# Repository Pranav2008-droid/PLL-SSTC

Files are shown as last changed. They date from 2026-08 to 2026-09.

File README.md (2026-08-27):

# PLL SSTC

## Overview
The PLL SSTC stands for Phase Locked Loop Solid State Tesla coil. This device produces high voltage sparks that resemble lightning by exciting a secondary coil at its resonant frequency.

This system tracks the resonant frequency using a Phase Locked Loop (PLL) IC: CD4046. It uses the output from the PLL to drive a full bridge switching circuit at around 300-325VDC.

It also has the capability to play audio through both Amplitude Modulation (AM) and Frequency Modulation (FM). It operates at 250kHz and should switch power in the Kilowatt range.




> ⚠️ High Voltage Warning  
> This project involves potentially lethal voltages and high-frequency/high-power switching. Do not build or operate it unless you understand the relevant electrical safety risks.

## Gate Driver
I'm using a TC4428 paired with 2 N-channel/P-channel dual MOSFET ICs to produce an amplified signal capable of producing higher driving currents. Any MOSFET driving IC with one inverting and one non-inverting output should work in the PCB, such as the UCC27425.

## GDT
The Gate Drive Transformer must be large enough to not saturate from driving currents and be of the correct material to work properly under such high frequencies.

## Mosfets
My circuit shows IRFP460s as the full bridge switches, but they are a bit outdated and inefficient. Much better alternatives exist — IGBTs can also be used instead.

## Primary
Make sure the primary impedance is high enough such that your switches can handle the currents.

## Demo
Demo of the amplitude modification music played through an attiny interupter: https://www.youtube.com/shorts/cHrE9xm2R9Q

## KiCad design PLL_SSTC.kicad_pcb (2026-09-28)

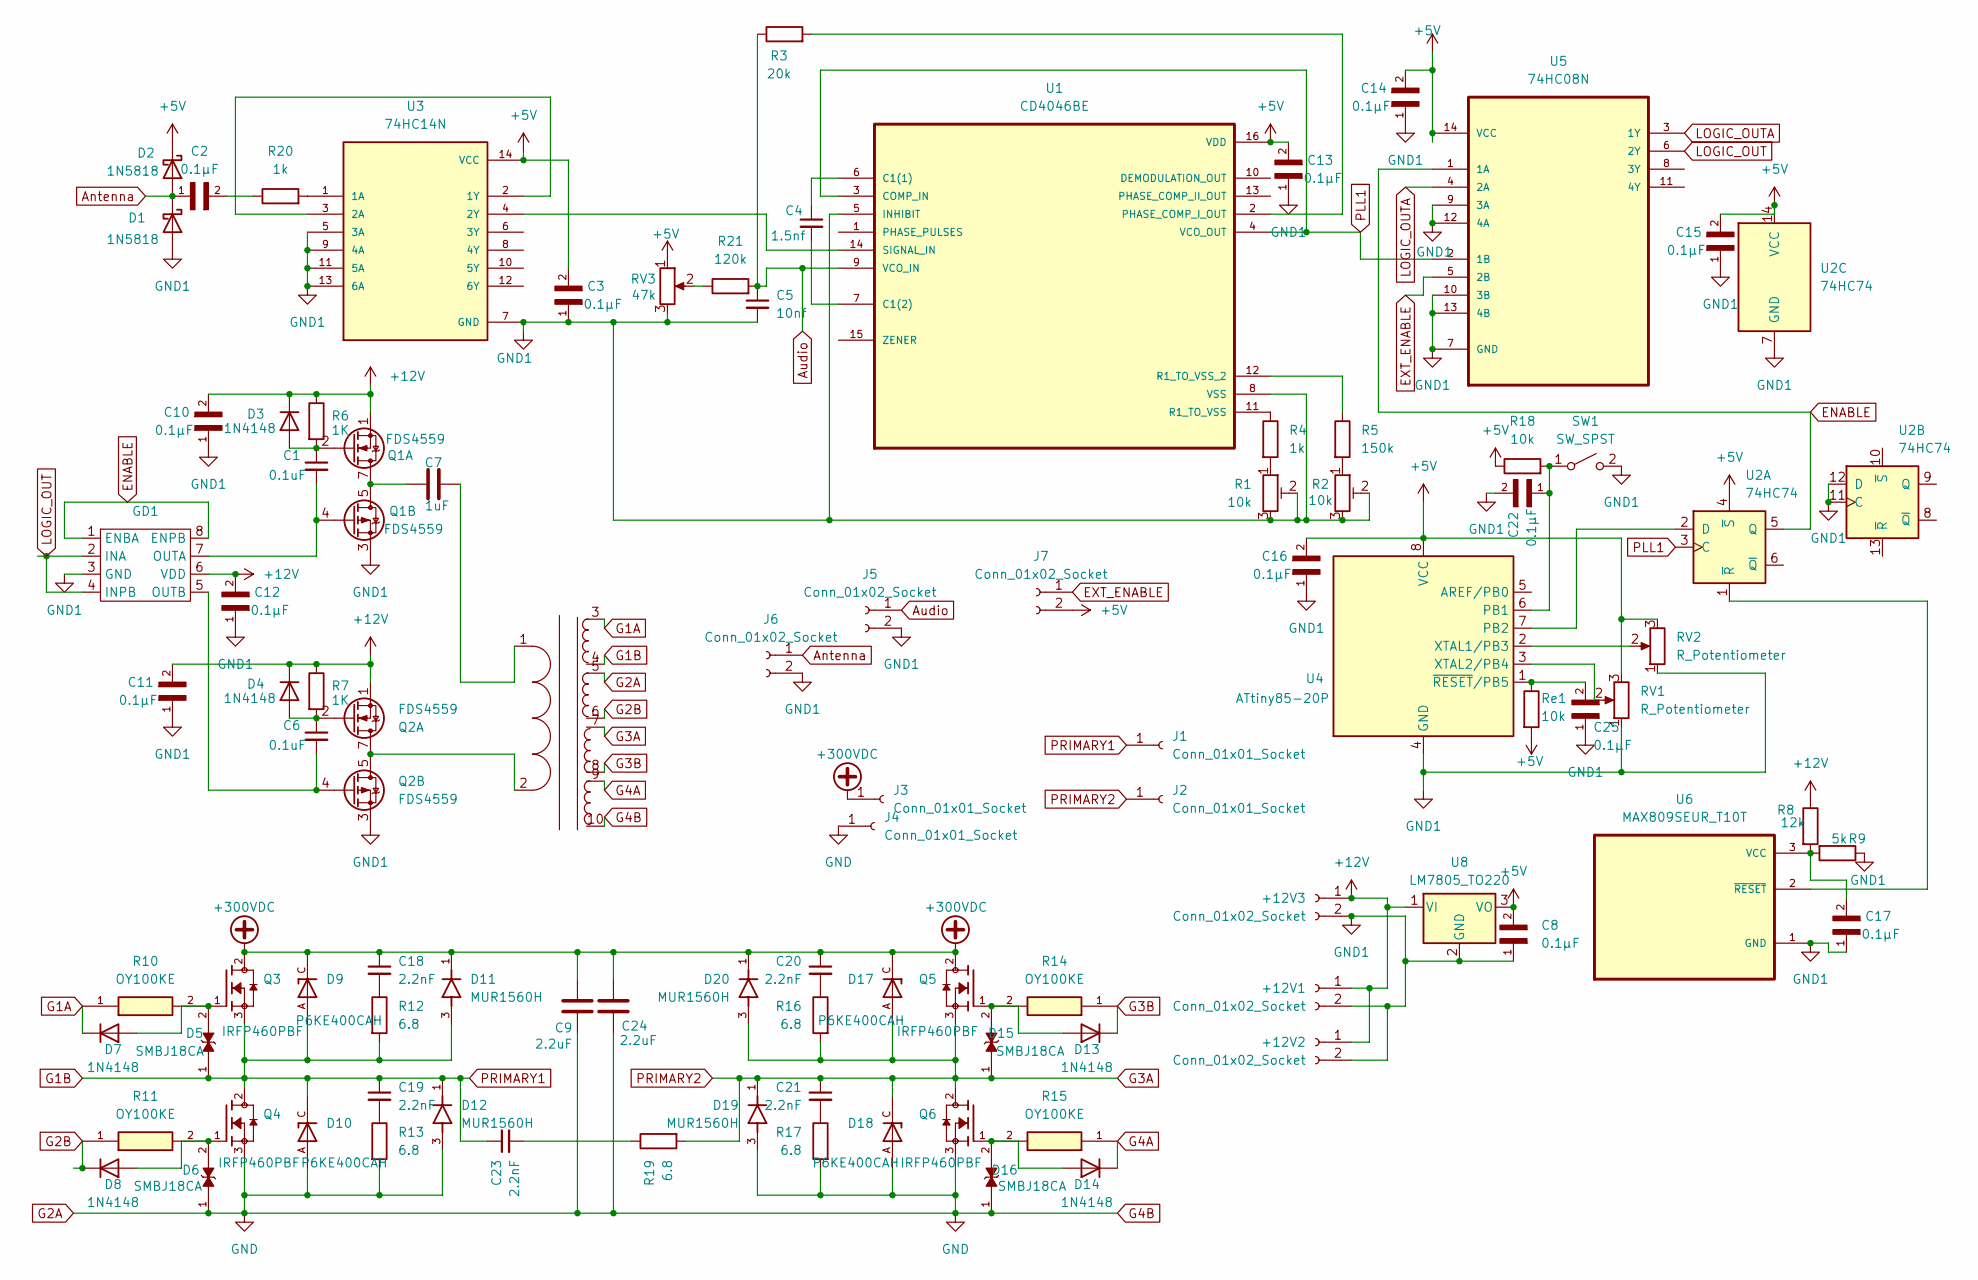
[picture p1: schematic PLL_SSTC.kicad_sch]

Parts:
+12V1, +12V2, +12V3: Conn_01x02_Socket; PinHeader_1x02_P2.54mm_Vertical
C1, C6: 0.1uF; C_0603_1608Metric_Pad1.08x0.95mm_HandSolder
C2, C3, C8, C10, C11, C12, C13, C14, C15, C16, C17, C22, C25: 0.1µF; C_0603_1608Metric_Pad1.08x0.95mm_HandSolder; PARTREV 081816
C4: 1.5nf; C_Rect_L7.0mm_W2.5mm_P5.00mm
C5: 10nf; C_Rect_L7.0mm_W2.5mm_P5.00mm
C7: 1uF; C_Rect_L31.5mm_W15.0mm_P27.50mm_MKS4
C9, C24: 2.2uF; C_Rect_L31.5mm_W15.0mm_P27.50mm_MKS4
C18, C19, C20, C21, C23: 2.2nF; C_Rect_L7.0mm_W2.5mm_P5.00mm
D1, D2: 1N5818; D_DO-41_SOD81_P10.16mm_Horizontal
D3, D4, D7, D8, D13, D14: 1N4148; D_DO-35_SOD27_P7.62mm_Horizontal
D5, D6, D15, D16: SMBJ18CA; DIOM4336X265N; PARTREV I2102
D9, D10, D17, D18: P6KE400CAH; DIOAD1300W80L670D310; PARTREV K2105
D11, D12, D19, D20: MUR1560H; TO508P997X444X1905-2; PARTREV F
GD1: DIP-8_W7.62mm_LongPads
J1, J2, J3, J4: Conn_01x01_Socket; SolderWire-4sqmm_1x01_D3mm_OD6mm
J5, J6, J7: Conn_01x02_Socket; TerminalBlock_Phoenix_MKDS-3-2-5.08_1x02_P5.08mm_Horizontal
Q1, Q2: FDS4559; SOIC-8_3.9x4.9mm_P1.27mm
Q3, Q4, Q5, Q6: IRFP460PBF; TO546P1587X531X2511-3; PARTREV A
R1, R2: 10k; TRIM_3296W-1-250
R3: 20k; R_Axial_DIN0207_L6.3mm_D2.5mm_P10.16mm_Horizontal
R4, R20: 1k; R_Axial_DIN0207_L6.3mm_D2.5mm_P10.16mm_Horizontal
R5: 150k; R_Axial_DIN0207_L6.3mm_D2.5mm_P10.16mm_Horizontal
R6, R7: 1K; R_Axial_DIN0207_L6.3mm_D2.5mm_P10.16mm_Horizontal
R8: 12k; R_Axial_DIN0207_L6.3mm_D2.5mm_P10.16mm_Horizontal
R9: 5k; R_Axial_DIN0207_L6.3mm_D2.5mm_P10.16mm_Horizontal
R10, R11, R14, R15: OY100KE; R_Axial_DIN0414_L11.9mm_D4.5mm_P7.62mm_Vertical; MOUSER_PART_NUMBER 588-OY-10-E
R12, R13, R16, R17, R19: 6.8; R_Axial_DIN0922_L20.0mm_D9.0mm_P7.62mm_Vertical
R18: 10k; R_Axial_DIN0207_L6.3mm_D2.5mm_P10.16mm_Horizontal
R21: 120k; R_Axial_DIN0207_L6.3mm_D2.5mm_P10.16mm_Horizontal
RV1, RV2: R_Potentiometer; Potentiometer_Bourns_3296X_Horizontal
RV3: 47k; Potentiometer_Bourns_3296X_Horizontal
Re1: 10k; R_Axial_DIN0204_L3.6mm_D1.6mm_P1.90mm_Vertical
SW1: SW_SPST; TerminalBlock_4Ucon_1x02_P3.50mm_Horizontal
U1: CD4046BE; DIP794W45P254L1969H508Q16
U2: 74HC74; CERDIP-14_W7.62mm_SideBrazed_LongPads_Socket
U3: 74HC14N; DIP764W47P254L1920H431Q14
U4: ATtiny85-20P; DIP-8_W7.62mm
U5: 74HC08N; DIP254P762X420-14; MPN 74HC08N
U6: MAX809SEUR_T10T; SOT95P237X112-3N
U7: GDT_1P4S
U8: LM7805_TO220; TO-220-3_Vertical

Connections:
+5V: C3.2, C8.2, C13.2, C14.2, C15.2, C16.2, D2.1 (K), J7.2, R18.1, RV1.3, RV2.3, RV3.1, Re1.2, U1.16 (VDD), U2.4 (~S), U2.14 (VCC), U3.14 (VCC), U4.8 (VCC), U5.14 (VCC), U8.3 (VO)
+12V: +12V1.1, +12V2.1, +12V3.1, C10.2, C11.2, C12.2, D3.1 (K), D4.1 (K), GD1.6 (VDD), Q1.1 (S1), Q2.1 (S1), R6.1, R7.1, R8.1, U8.1 (VI)
+300VDC: C9.1, C18.1, C20.1, C24.1, D9.C, D11.1, D17.C, D20.1, J3.1 (Pin_1_1), Q3.2, Q5.2
Antenna: C2.1, D1.1 (K), D2.2 (A), J6.1
Audio: C5.1, J5.1, R3.1, R21.2, U1.9 (VCO_IN)
ENABLE: GD1.1 (ENBA), GD1.8 (ENPB), U2.5 (Q), U5.1 (1A)
EXT_ENABLE: J7.1, U5.5 (2B)
G1A: D7.1 (K), R10.1, U7.3 (1A)
G1B: C19.1, C23.1, D5.1, D9.A, D10.C, D11.3, D12.1, J1.1 (Pin_1_1), Q3.3, Q4.2, R12.2, U7.4 (1B)
G2A: C9.2, C24.2, D6.1, D10.A, D12.3, D16.1, D18.A, D19.3, J4.1 (Pin_1_1), Q4.3, Q6.3, R13.2, R17.2, U7.5 (2A), U7.10 (4B)
G2B: D8.1 (K), R11.1, U7.6 (2B)
G3A: C21.1, D15.1, D17.A, D18.C, D19.1, D20.3, J2.1 (Pin_1_1), Q5.3, Q6.2, R16.2, R19.2, U7.7 (3A)
G3B: D13.1 (K), R14.1, U7.8 (3B)
G4A: D14.1 (K), R15.1, U7.9 (4A)
GND1: +12V1.2, +12V2.2, +12V3.2, C3.1, C5.2, C8.1, C10.1, C11.1, C12.1, C13.1, C14.1, C15.1, C16.1, C17.1, C22.2, C25.1, D1.2 (A), GD1.3 (GND), J5.2, J6.2, Q1.3 (S2), Q2.3 (S2), R1.2, R1.3, R2.2, R2.3, R9.1, RV1.1, RV2.1, RV3.3, SW1.2 (B), U1.5 (INHIBIT), U1.8 (VSS), U2.7 (GND), U2.11 (C), U2.12 (D), U3.5 (3A), U3.7 (GND), U3.9 (4A), U3.11 (5A), U3.13 (6A), U4.4 (GND), U5.7 (GND), U5.9 (3A), U5.10 (3B), U5.12 (4A), U5.13 (4B), U6.1 (GND), U8.2 (GND)
LOGIC_OUT: GD1.2 (INA), GD1.4 (INPB), U5.6 (2Y)
LOGIC_OUTA: U5.3 (1Y), U5.4 (2A)
unnamed: C2.2, R20.1
unnamed: C7.1, Q1.5 (D2), Q1.6 (D2), Q1.7 (D1), Q1.8 (D1)
unnamed: C18.2, R12.1
unnamed: C19.2, R13.1
unnamed: C20.2, R16.1
unnamed: C21.2, R17.1
unnamed: C23.2, R19.1
unnamed: C1.1, D3.2 (A), Q1.2 (G1), R6.2
unnamed: C6.1, D4.2 (A), Q2.2 (G1), R7.2
unnamed: D5.2, D7.2 (A), Q3.1, R10.2
unnamed: D6.2, D8.2 (A), Q4.1, R11.2
unnamed: D13.2 (A), D15.2, Q5.1, R14.2
unnamed: D14.2 (A), D16.2, Q6.1, R15.2
unnamed: C1.2, GD1.7 (OUTA), Q1.4 (G2)
unnamed: C6.2, GD1.5 (OUTB), Q2.4 (G2)
unnamed: R1.1, R4.2
unnamed: R2.1, R5.2
unnamed: R21.1, RV3.2
unnamed: C22.1, R18.2, SW1.1 (A), U4.6 (PB1)
unnamed: C4.1, U1.6 (C1(1))
unnamed: C4.2, U1.7 (C1(2))
unnamed: R3.2, U1.2 (PHASE_COMP_I_OUT)
unnamed: R4.1, U1.11 (R1_TO_VSS)
unnamed: R5.1, U1.12 (R1_TO_VSS_2)
unnamed: U1.14 (SIGNAL_IN), U3.4 (2Y)
unnamed: U2.2 (D), U4.7 (PB2)
unnamed: U2.1 (~R), U6.2 (~RESET)
unnamed: R20.2, U3.1 (1A)
unnamed: U3.2 (1Y), U3.3 (2A)
unnamed: RV2.2, U4.2 (XTAL1/PB3)
unnamed: RV1.2, U4.3 (XTAL2/PB4)
unnamed: C25.2, Re1.1, U4.1 (~RESET/PB5)
unnamed: C17.2, R8.2, R9.2, U6.3 (VCC)
unnamed: C7.2, U7.1 (PA)
unnamed: Q2.5 (D2), Q2.6 (D2), Q2.7 (D1), Q2.8 (D1), U7.2 (PB)
PLL1: U1.3 (COMP_IN), U1.4 (VCO_OUT), U2.3 (C), U5.2 (1B)

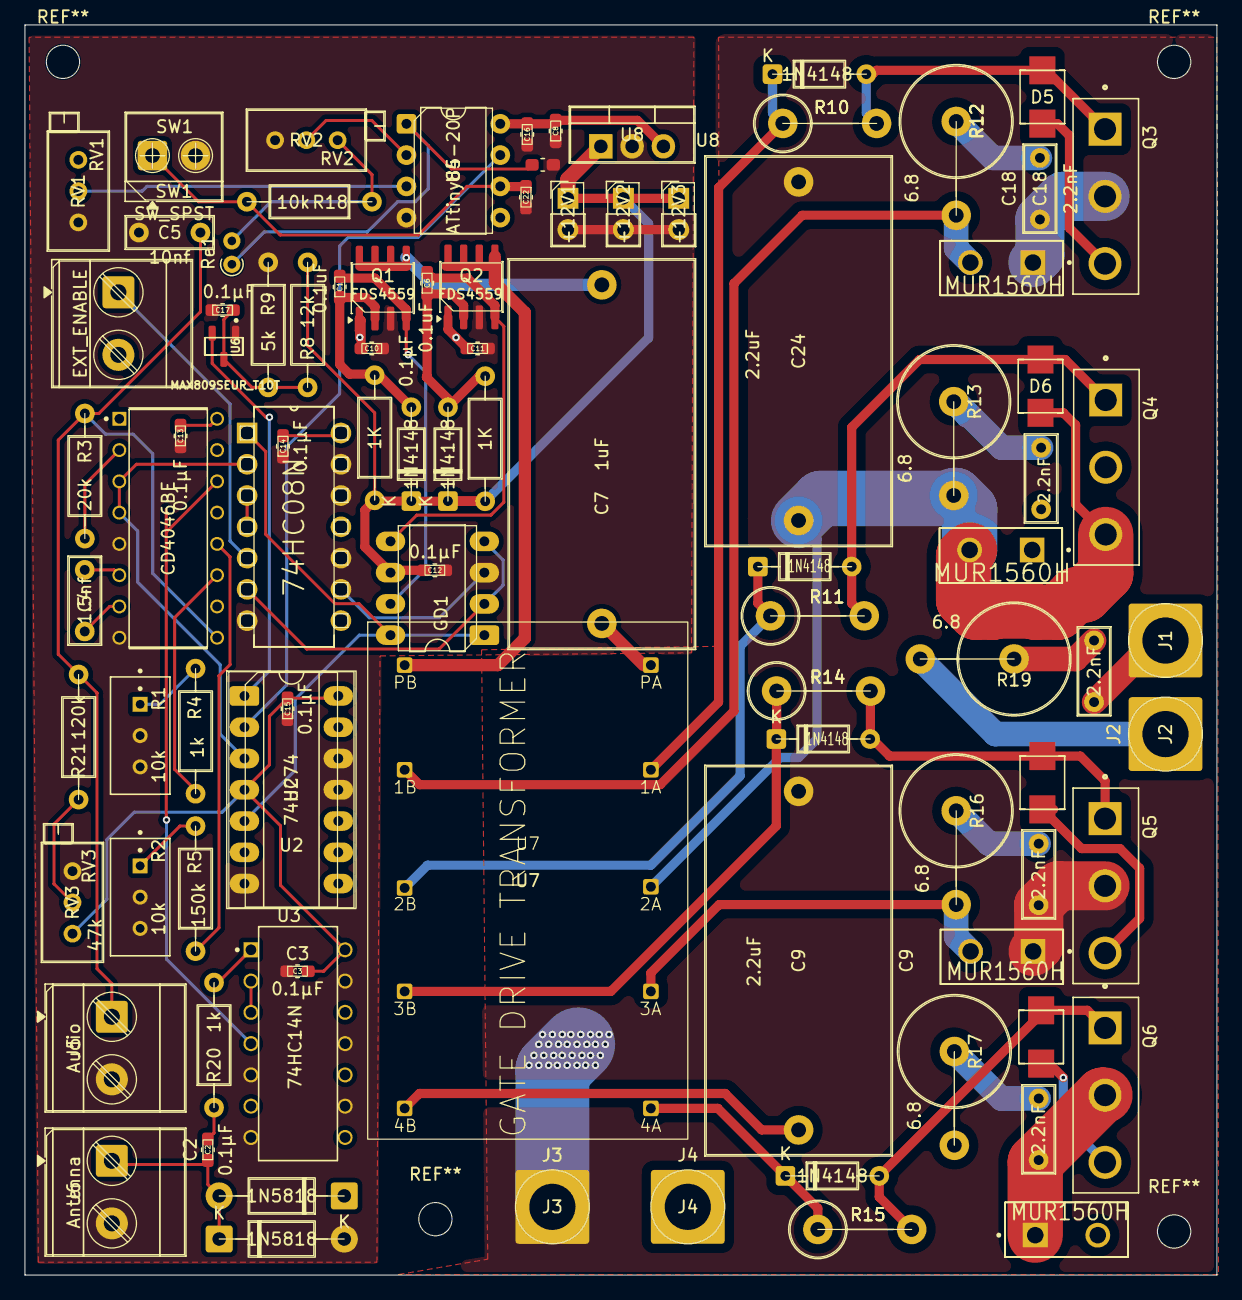
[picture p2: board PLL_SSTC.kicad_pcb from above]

Board: 2 copper layers, 96.8 x 101.5 mm, 92 parts (0 on the bottom side), 53 nets.

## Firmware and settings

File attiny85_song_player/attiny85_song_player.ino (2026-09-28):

/*
 * ATtiny85 SSTC Interrupter (Fixed Tempo, Volume-Only Control)
 * -------------------------------------------------------------------------
 * Pin Map:
 *   A3 (PB3) - Volume / Pulse-Width Potentiometer
 *   D1 (PB1) - Output to Gate Driver / Optocoupler
 * -------------------------------------------------------------------------
 */

#include <avr/io.h>
#include <avr/pgmspace.h>
#include <avr/wdt.h>

#include "song_data.h"

// ---------------- Pin Assignments ----------------
const uint8_t VOL_PIN  = A3;  // Volume pot only
const uint8_t GATE_PIN = 1;   // PB1 -> Optocoupler / Driver

// ---------------- 300V Safety Constraints ----------------
const uint16_t MIN_ON_TIME_US      = 100;  // Minimum for arc breakdown
const uint16_t ABSOLUTE_MAX_ON_US  = 1000; // 1ms pulse width ceiling
const uint16_t MIN_OFF_TIME_US     = 150;  // Gate discharge margin
const uint8_t  MAX_DUTY_CYCLE_PERC = 10;   // Dynamic 10% duty cycle cap

void setup() {
  wdt_disable(); // Watchdog disabled to prevent RF reset loops
  
  pinMode(GATE_PIN, OUTPUT);
  digitalWrite(GATE_PIN, LOW);
  
  pinMode(VOL_PIN, INPUT);
}

void loop() {
  playCompressedSong(full_midi_song, full_midi_song_len);
  delay(1500); // 1.5s delay before repeating
}

void playCompressedSong(const CompressedNote *song, uint16_t len) {
  for (uint16_t i = 0; i < len; i++) {
    uint8_t noteIdx = pgm_read_byte(&song[i].note_idx);
    uint8_t ticks   = pgm_read_byte(&song[i].ticks);
    
    uint16_t freq   = pgm_read_word(&note_freqs[noteIdx]);
    uint32_t dur_ms = (uint32_t)ticks * BASE_TICK_MS; // Fixed 1:1 speed

    playNote(freq, (uint16_t)dur_ms);
    
    digitalWrite(GATE_PIN, LOW);
    
    // Staccato articulation gap between notes
    uint32_t restTime = dur_ms / 10;
    if (restTime > 0) {
      delay(restTime);
    }
  }
}

void playNote(uint16_t freq, uint16_t duration_ms) {
  if (freq == 0 || duration_ms == 0) {
    digitalWrite(GATE_PIN, LOW);
    if (duration_ms > 0) delay(duration_ms);
    return;
  }

  uint32_t periodUs = 1000000UL / freq;
  
  // Calculate dynamic 10% duty cycle limit per note pitch
  uint32_t dutyMaxOn = (periodUs * MAX_DUTY_CYCLE_PERC) / 100;
  uint32_t hardMaxOn = (periodUs > MIN_OFF_TIME_US) ? (periodUs - MIN_OFF_TIME_US) : 0;
  
  uint16_t safeMaxOnTime = ABSOLUTE_MAX_ON_US;
  if (dutyMaxOn < safeMaxOnTime) safeMaxOnTime = (uint16_t)dutyMaxOn;
  if (hardMaxOn < safeMaxOnTime) safeMaxOnTime = (uint16_t)hardMaxOn;

  if (safeMaxOnTime < MIN_ON_TIME_US) {
    safeMaxOnTime = MIN_ON_TIME_US;
  }

  // Read volume potentiometer and enforce safety cap
  uint16_t requestedOnTime = readVolumePulseWidth();
  uint16_t onTime = (requestedOnTime > safeMaxOnTime) ? safeMaxOnTime : requestedOnTime;

  if (onTime >= periodUs) {
    onTime = periodUs / 2;
  }

  uint32_t offTime = periodUs - onTime;
  uint32_t numCycles = ((uint32_t)duration_ms * 1000UL) / periodUs;

  for (uint32_t i = 0; i < numCycles; i++) {
    digitalWrite(GATE_PIN, HIGH);
    delayMicroseconds(onTime);
    
    digitalWrite(GATE_PIN, LOW);
    
    uint32_t remainingOff = offTime;
    while (remainingOff > 10000) {
      delayMicroseconds(10000);
      remainingOff -= 10000;
    }
    delayMicroseconds(remainingOff);
  }
  
  digitalWrite(GATE_PIN, LOW);
}

// Reads Volume Potentiometer (A3) with floor & noise filtering
uint16_t readVolumePulseWidth() {
  uint32_t sum = 0;
  for (uint8_t i = 0; i < 4; i++) {
    sum += analogRead(VOL_PIN);
  }
  uint16_t raw = sum / 4;
  uint16_t val = map(raw, 0, 1023, MIN_ON_TIME_US, ABSOLUTE_MAX_ON_US);
  return (val < MIN_ON_TIME_US) ? MIN_ON_TIME_US : val;
}

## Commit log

2026-08-24 Enhance README with images and safety warning
    Added images and a high voltage warning to README.
2026-09-27 fixed power connections and added mounting holes
    [PLL_SSTC-B_Cu.gbr, PLL_SSTC-B_Mask.gbr, PLL_SSTC-B_Paste.gbr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]
2026-09-28 updated drills and attiny file
    [PLL_SSTC-B_Cu.gbr, PLL_SSTC-B_Mask.gbr, PLL_SSTC-B_Paste.gbr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]
